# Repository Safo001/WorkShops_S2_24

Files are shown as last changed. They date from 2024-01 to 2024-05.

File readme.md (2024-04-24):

# WorkShops
## 1. [Build your Drone controller based on ESP-NOW](./workshop1/readme.md)
## 2. [CAD Design](https://github.com/UBRoboticsWorkshop/WorkShops_S2_24/tree/main/workshop2)
## 3. [Air Unit](https://github.com/UBRoboticsWorkshop/WorkShops_S2_24/tree/main/workshop3)
## 4. [Assembly and Power](https://github.com/UBRoboticsWorkshop/WorkShops_S2_24/tree/main/workshop4)

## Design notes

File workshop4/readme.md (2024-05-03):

# Assembling and Testing Your Drone
Firstly, make sure that you have all of your parts:

- Air unit
- 2x silver motors
- 2x black motors
- 4x propellers
- Capacitor
- ESC cable
- Air Unit
- 4 * Yellow Grommits
- Battery Cable

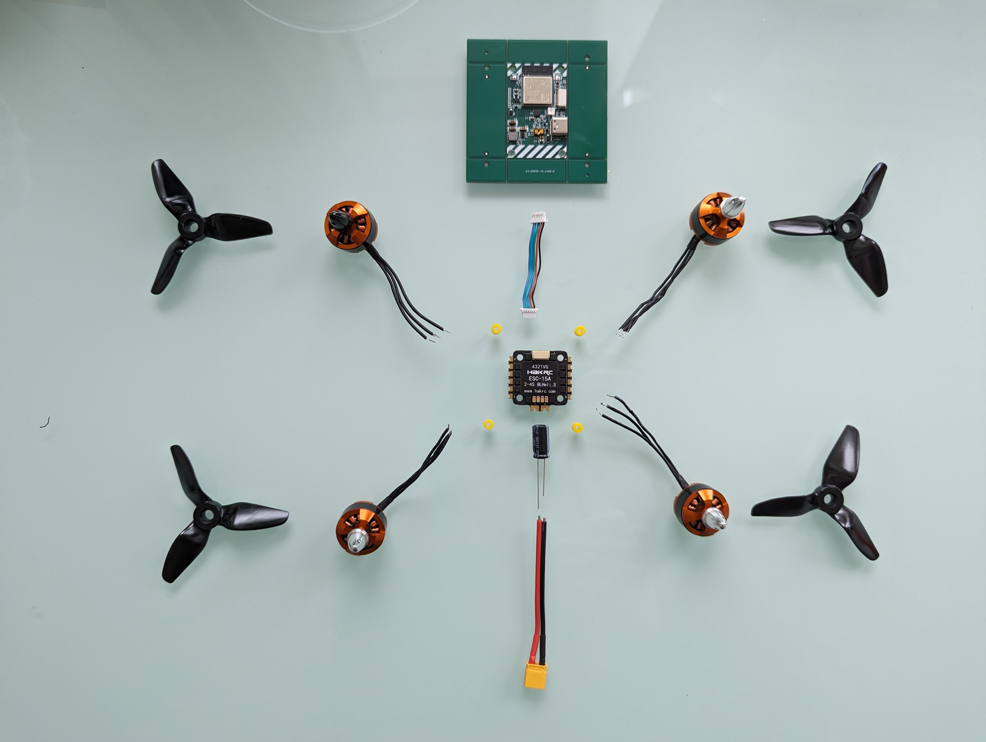
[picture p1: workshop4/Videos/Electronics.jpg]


And the printed parts:

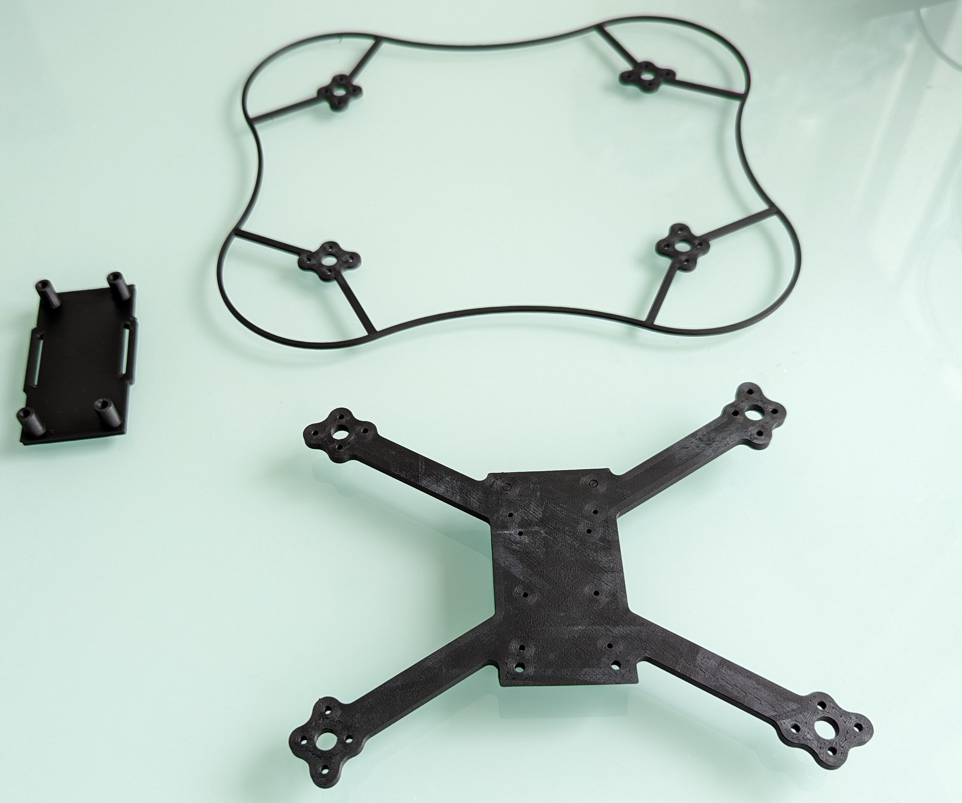
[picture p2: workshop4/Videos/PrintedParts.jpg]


- Propeller Guards
- Frame
- Battery mount

# Assembly 
Get your Air Unit ready by snaping off the rails, if you haven't already. 

Push 4 grommits into the Air Unit board. This can be a bit difficult, try squishing the grommit to squeeze it through the board.

https://github.com/UBRoboticsWorkshop/WorkShops_S2_24/assets/20403882/7c90dd00-24de-48df-a7dd-f99b9ae6fdc1

Remove the LiDAR cover, a thin orange file. Check carefully if it has already fallen off, otherwise you may scratch the LiDAR.

https://github.com/UBRoboticsWorkshop/WorkShops_S2_24/assets/20403882/bb20e618-9f44-439a-a1e0-7cc39bd59e51

Fit the ESC connector.

https://github.com/UBRoboticsWorkshop/WorkShops_S2_24/assets/20403882/d694c8c8-acc0-4bfe-938f-f40fce734783

Place the Air Unit into the cavity on the bottom of the frame, and use four M2 bolts to secure it.

https://github.com/UBRoboticsWorkshop/WorkShops_S2_24/assets/20403882/95f320fe-4e49-4986-b4f0-f9991f88dea0

Push 4 grommits into the 4 in 1 ESC.

https://github.com/UBRoboticsWorkshop/WorkShops_S2_24/assets/20403882/dd1053c3-97e8-4211-8c61-10d019f4d6c8

Use 4 M2 bolts to secure the 4 in 1 ESC to the top of the frame.

https://github.com/UBRoboticsWorkshop/WorkShops_S2_24/assets/20403882/43d65e90-b0f7-4e27-866d-42bc7dd63a49

Plug in the ESC cable

https://github.com/UBRoboticsWorkshop/WorkShops_S2_24/assets/20403882/b021f05e-f96a-4259-94c4-3d8d9a3c5d0e

Push some bolts through the frame and the guard, so as to align them. Next, screw the motor down onto it.

https://github.com/UBRoboticsWorkshop/WorkShops_S2_24/assets/20403882/b7a73cb8-1e47-4572-9239-a0372c5feb96

### Important! The motor nut propeller colours need to the in the same positions as in the videos, as they determine spin direction!

Solder on the motor wires. The best way to do this is to use your soldering stand to hold the wire against the side of the pad, such that the springiness of the wire puts a slight amount of pressure on the ESC. Clean your iron on the stand, before applying a very small amount of solder to the iron. This solder isn't to secure the wire, but to allow the liquid solder to better transfer heat than a dry iron. Let the pad heat up before you add more solder, and then hold the iron on the pad until the solder flows across it.

https://github.com/UBRoboticsWorkshop/WorkShops_S2_24/assets/20403882/3827fa9a-afa0-4dfc-aa05-6e3b26d2da30

https://github.com/UBRoboticsWorkshop/WorkShops_S2_24/assets/20403882/65c0ad6d-4bae-456d-b40d-aabbf710668b

Make sure to consider the angle you're soldering from. Put the iron on the side of the ESC away from the components, to reduce the risk of burning them.

The second best, but sometimes needed, way to solder on the wires is by first addind solder to the pad and then melting it while pressing the wire into it. Make sure that the insulation of the wire doesn't touch the solder, and be aware that the wire might heat up. This is a slightly questionable technique, but it's the easiest way to get the job done.

https://github.com/UBRoboticsWorkshop/WorkShops_S2_24/assets/20403882/1eaa0f6d-09d4-4b70-82b8-a107138e61ee

Next, solder the XT30 battery connector and capacitor to the ESC. Trim down the capacitor legs, and strip the insulation back on the battery wires. 

https://github.com/UBRoboticsWorkshop/WorkShops_S2_24/assets/20403882/044b5c15-248d-48de-9cad-c10328447741

Press the capacitor legs through the holes in the ESC pads, making sure that the polarity is correct (The capacitor will have a stripe to indicate negative, with minus signs on it. There should also be polarity markings on the ESC). Use the second hand to position the wire on the outside of the pad, and solder it down.

https://github.com/UBRoboticsWorkshop/WorkShops_S2_24/assets/20403882/d0c8200d-6cd6-4b8d-8212-d3770a6cd13c

Once you're sure the soldering is complete, mount the top part. If in doubt about a joint, call us over to check the joint before testing. 

https://github.com/UBRoboticsWorkshop/WorkShops_S2_24/assets/20403882/15de63a5-3043-421d-8a90-f4572b7fb201

# Testing
To test the power systems, we'll first use the bench supply. The main benefit of this is that a short circuit will cause a current cap rather than an explosion. Set the current to 500mA, to mitigate how much current can flow in this case, and the voltage to 11.1v. 

### Do not run the motors with the propellers connected! 

Upload the ESC testing sketech to the Air Unit, and disconnect the air unit from the computer. The system will now try to spin its motors 2.5 seconds after being connected to power.

Use the male XT30 connector with two leads soldered onto it to connect the bench supply, paying careful attention to the polarity. 

https://github.com/UBRoboticsWorkshop/WorkShops_S2_24/assets/20403882/5a78b0ef-956f-4ef9-ad18-9214dca81df2

The ESC will emit a series of beeps, then spin up the motors. Look closely at the screw threads on the motor outputs- They should be screwing downwards, like in this video:

https://github.com/UBRoboticsWorkshop/WorkShops_S2_24/assets/20403882/88b82665-31b5-4852-8465-4818063c72b0

If a motor is spinning backwards, it can be reversed by simply swapping two of the motor's wires. On a BLDC motor such as this, it doesn't matter which pair of wires are swapped- swapping any two will reverse it. You can use the technique described earlier of heating a solder blob and then inserting the wire to do this quickly.

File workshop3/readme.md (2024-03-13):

# Using the Air Unit

The Air Unit is similar to the ESP32 development board from Sumobots, however with additional systems on board to support flight. Some of the features of the Air Unit include:

- LiDAR, for millimetre altitude control
-	IMU, for rotation sensing to stabilize flight
-	Switching regulator, to allow direct supply from lithium batteries
-	8 GPIO pins broken out- these have a very small spacing though, so only try to use these if you’re very confident in soldering
-	USB-C, because at UBRobotics we live large 
-	RGB LED, added because our President Aswathy is a Gamer and she threatened to kick me off the committee if I didn’t make the drones replicate the exact colour fade she uses on her Cherry MX 2.0S Red Gaming Keyboard (with mechanical switches). Making the LED cover the full Adobe Wide Gamut RGB was the hardest part of the design, so you’d better appreciate it.

Through this tutorial, make sure to use the [code glossary](./CodeGlossary.md) included. 

# Step 1: Connect to the ESP32-S3
For this part, make a new sketch.

The Air Unit uses an ESP32-S3, which is a major upgrade from the base ESP32. One of the benefits is direct connection to USB, without a programming chip.

However, you’ll need to bootstrap it the first time. You can do this simply by holding down the BOOT button as you plug it in, to put it into boot mode. In this mode, it won’t run any code- it’ll just wait for a download.

Now you should see a port available for download and can proceed as normal. Under “Tools”, set the following settings:

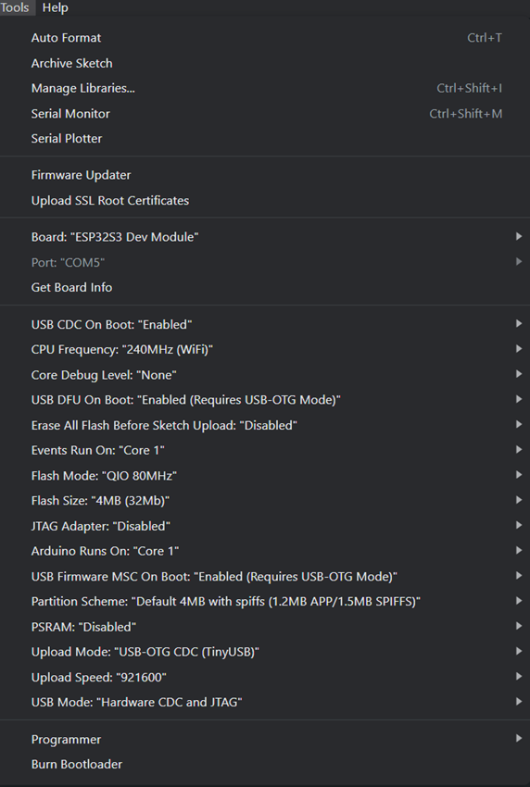
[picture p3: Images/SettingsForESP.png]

 
Hit upload with a blank sketch to save these settings to the ESP32-S3. If you can’t get the board to print text, make sure these settings are correct.

# Step 2: Hello World
From here, you can make an new sketch and write a simple “Hello World” program to check that the ESP32-S3 is working:

```cpp

void setup() {
  Serial.begin(115200);
}

void loop() {
  Serial.println("Hello World");
}
```

If successful, the unit will print Hello World very quickly into the serial monitor- the system is working. 

However, if you attempt to upload a new sketch you will probably see something like this:

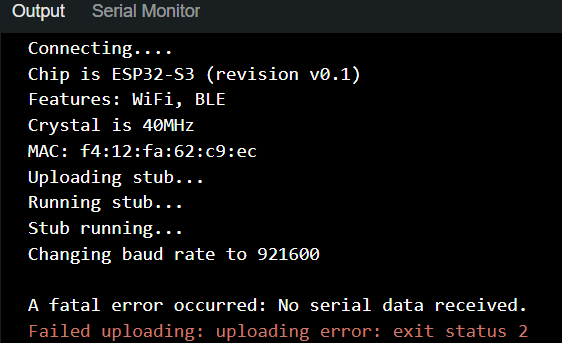
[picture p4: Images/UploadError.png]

 
This is because the USB connection is overloaded. This is a possible issue with the ESP32-S3 onboard USB, but it can be fixed by using the BOOT button.

Add a 1000ms delay into the sketch after the print statement, and then unplug the ESP32-S3. Hold down the button marked BOOT, plug in the USB cable and then release the BOOT button. You should be able to see this message in the serial terminal:

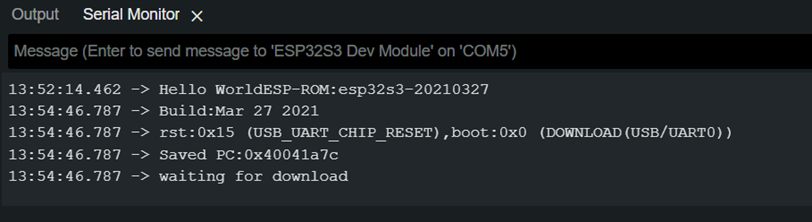
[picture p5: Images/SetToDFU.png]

 
Uploading should now be successful, and the program will run after you reboot the ESP32-S3- this time printing the text once per second. From here, you can upload the code without using the BOOT button. If there are issues with uploading to the ESP32-S3, try the BOOT button to recover it.

When working with UAVs, the main loop will run thousands of times per second, which means a print statement in the main loop can cause the ESP32-S3 to lock up.

You can also tap the reset button instead of unplugging the Air Unit.

# Step 3: Using the LED

This section is on the LED_TEST sketch.

Unlike the LEDs last semester, the Air Unit has a WS2812 addressable LED allowing digital colour and brightness control. It’s also a little bit brighter than a regular LED.

Use ```neopixelWrite()``` to set the colour of the LED, which is connected to pin 48. 

You can use ```(brightness+brightness*sin(i)/2)``` to have the brightness of each channel fade smoothly between zero and brightness.

```cpp
const int brightness = 27;

void setup() {
 
}

float i;
void loop() {
  delay(10);
  i+=0.1;
  //Put your neopixel code here
}
```

To test how long this command takes, create a variable called:

```long startTime, endTime;```

Set ```startTime``` to ```micros()``` before the code to be measured, and ```endTime``` to ```micros()``` once it has run. You can then read out the difference between the two out on the serial monitor. How long does this command take?

For dynamic systems, it’s important to make sure that your code can run fast enough to react to changes in the environment. The ESP32 has two cores, so you can put code like this which isn’t time critical on one, and the more important code on the other.

# The IMU

Simple sensors, such as a thermistor, use analog signals to communicate; in more advanced systems it’s common to find serial communications used. The Inertial Measurement Unit (IMU) on this board uses Serial Peripheral Interface (SPI) to communicate.

## Registers

Most serial devices use what is known as a register map. The register map for the MPU6500 can be found [here](https://invensense.tdk.com/download-pdf/mpu-6500-register-map)

A register map is like a table, where each “register” is a location which holds a value- these are effectively variables stored on the sensor. These values can either control the behaviour of the sensor, or hold information to be read. Some registers can be both written and read, while others have controlled access.

## SPI
The Serial Peripheral Interface uses four lines:

<img width="600" src="https://github.com/UBRoboticsWorkshop/WorkShops_S2_24/blob/main/Images/SPI.png">
 
Credit: Analog Devices

•	The CS line allows for a device to be selected without an address being broadcast, which saves time
•	MOSI is data travelling out from the ESP32-S3
•	MISO is data travelling out from the IMU
•	SCLK is the clock signal, which allows for data to be read on the MOSI/MISO lines at the right time

The IMU can run SPI at 2,000,000 bits per second for all of its registers, and 20,000,000 for the main data registers.

If you want to learn more about SPI, have a look at [this](https://learn.sparkfun.com/tutorials/serial-peripheral-interface-spi/programming-for-spi)

# Step 4: Reading From the IMU	

This section is in the IMU_CONNECT sketch.

The following is a snippet of code that is used to check the IMU is working before the aircraft takes off:

```cpp
// IMU Check Before Takeoff

#include <SPI.h>

#define MPU6500_NCS 18
#define MPU6500_ID 0x70
#define WHO_AM_I_REG 117
#define READ_BIT_MASK 0x80

SPIClass *IMUHSpi = NULL;

void setup() {
  Serial.begin(115200);

  IMUHSpi = new SPIClass(FSPI);
  setupIMUSPI(IMUHSpi);

  if (readIMURegister(WHO_AM_I_REG) != MPU6500_ID) {
    Serial.println("IMU not found. Takeoff may result in an unpleasant day.");
    Serial.print("WHO AM I register returned: 0x");
    Serial.println(readIMURegister(WHO_AM_I_REG), HEX);
    while (1) {
      ; // Halt program on error
    }
  } else {
    Serial.println("IMU found");
  }
}

void loop() {
  // Main loop
}

int readIMURegister(int registerAddress) {
  int readCommand = 0;
  int regData = 0;
  return regData;
}

void setupIMUSPI(SPIClass *IMUHSpi) {
  pinMode(MPU6500_NCS, OUTPUT);
  digitalWrite(MPU6500_NCS, HIGH);

  IMUHSpi->begin(17, 15, 16, 18);  // Customize these pin numbers as needed
  IMUHSpi->setFrequency(1000000);
  IMUHSpi->setDataMode(SPI_MODE0);
  IMUHSpi->setBitOrder(MSBFIRST);
}
```

In this code, the function ```readIMURegister()``` takes a register to read and returns the value of the register. 

Run this code, and check what is said in the serial monitor. The IMU won’t be found, because ```readIMURegister()``` doesn’t do anything (causing “ an unpleasant day”).

Using ```digtalWrite()``` and ```IMUHSpi->transfer()```:

1.	Set the NCS pin to low
2.	Send the register address with the first bit set to one (to indicate a write command) to the IMU
3.	Transfer 0x00 to the IMU, and save the response to regData to be returned 
4.	Set the NCS pin back to high

When it works, it should print “IMU found”. Some of the IMUs may return a value of ```0x71```, if this is the case just change the definition.

<details>
  <summary> <b> Hint: SPI comms  </b>  </summary>
  
To make this work, use ```digtalWrite()``` to set ```MPU6500_NCS``` (Pin 18) to LOW, which tells the IMU to expect communications. 

An outgoing message can be either a read command or a write command, identified by the first bit being a 1 for read or 0 for write.

registerAddress will be a value from 0-127. It’ll need to be a value from 128-255 to read. We can use Boolean operations to make this so- this is known as “setting a bit”. To set the leftmost bit to one, we can use: 

```cpp
registerAddress | 0b10000000
```

```0b``` tags the number as a binary number. However, this is not very readable so we can use hexadecimal instead.

```cpp
registerAddress | 0x80
```

This is the same number (127), but represented as hexadecimal. Using compiler commands we can make it even more readable. There is a line at the top of the sketch:

```cpp
#define READ_BIT_MASK 0x80
```

This line of code will not be uploaded to the ESP32 S3. Instead, it tells the compiler to replace every instance of "```READ_BIT_MASK```” with “```0x80```”. Be careful- it won’t take context into account! If you misuse compiler commands, for example defining a value for “int”, the compiler will replace every single “int” with this definition of it.

Use  ```IMUHspi->transfer()``` to send ```reg | 0x80```. Then, send ```0x00``` and save the number it returns to ```regData```. Note that because we’re using a pointer to refer to the SPI bus instead of using it directly, we use “->” rather than “.” to address member functions. 

Finally, set pin ```MPU6500_NCS``` to ```HIGH```, in order to end the communication.

</details>

# Step 5: Read Faster

Use the IMU_SEQUENTIAL_READ sketch for this part.

If we want to read the IMU data, there are 12 registers to read- 6 different values, with two bytes each. It’s not very quick to read each register, end the communication, start it again, address the next register, so on, so on.

Instead, we can simply read the first register and then keep sending ```0x00```. This will trigger a sequential read, moving down the register table each time. Not all devices support this, but all of the good ones do.

Annoyingly, Invensense decided to put thermometer data right in the middle of the data we actually care about. Great prank guys.

However, it’s still quicker to read all 14 bytes at once than two blocks of 6, so I guess your drone now doubles as an Internet of Things home assistant AI central heating blockchain enabled flying thermostat or something. 

Anyway, here’s the code:

```cpp
#include <SPI.h>

#define MPU6500_NCS 18
#define MPU6500_ACC_X_L 59
#define READ_BIT_MASK 0x80

SPIClass *IMUHSpi = NULL;
byte imuDataRawAccGyro[14];

void setup() {
  Serial.begin(115200);

  IMUHSpi = new SPIClass(FSPI);
  setupIMUSPI(IMUHSpi);
}

void loop() {
  readIMUSPI(59, 14, imuDataRawAccGyro);
  for (int i = 0; i < 14; i++) {
    Serial.print(imuDataRawAccGyro[i]);
    Serial.print("\t");
  }
  Serial.println();

  delay(250);
}

void readIMUSPI(int registerAddress, int count, byte data[]) {
	
}

void setupIMUSPI(SPIClass *IMUHSpi) {
  pinMode(MPU6500_NCS, OUTPUT);
  digitalWrite(MPU6500_NCS, HIGH);

  IMUHSpi->begin(17, 15, 16, 18);  // Customize these pin numbers as needed
  IMUHSpi->setFrequency(1000000);
  IMUHSpi->setDataMode(SPI_MODE0);
  IMUHSpi->setBitOrder(MSBFIRST);
}

```

Once again, fill in the blanks for ```readIMUSPI(int reg, int count, byte data[])```
1.	Pull CS low
2.	Send a register address, with first bit set to indicate “read”
3.	Iterate through the ```data[]``` array with a for loop, transferring ```0x00``` and storing the responses in ```data[i]```
4.	Pull CS low high to end the communication

Since all arrays are passed by reference, any changes made to ```data[]``` will persist outside ```readIMUSPI()```- there’s no need to return anything.

When this code works, you should see a ton of numbers being printed in the Serial terminal- they won’t seem to mean anything, but will change when the board is moved.

Except the two bytes for temperature. They’ll change when the temperature changes. Thanks Invensense.

# Step 6: Processing the Data

Keep using the IMU_SEQUENTIAL_READ sketch for this part.

The data is returned as a high byte and a low byte- these are two 8 bit numbers that can be concatenated (added end to end) in binary to form one signed 16 bit number, as shown below:

| | -32768 | 16384 | 8192 | 4096 | 2048 | 1024 | 512 | 256 | 128 | 64 | 32 | 16 | 8 | 4 | 2 | 1 |
|---|---|---|---|---|---|---|-----|-----|-----|----|----|----|--|---|---|---|
| High Byte | 1 | 0 | 0 | 1 | 1 | 0 | 1 | 0 | | | | |  | | | |
| Low Byte  | | | | | | | | | 1 | 1  | 1  | 0  | 1 | 0 | 1 | 1 |

the high byte is 10011010 in binary which represents 154 in decimal.

the low byte is 11101011 in binary which represents 235 in decimal.

When we add them together, the first bit becomes negative creating -25877 in decimal.

The reason the numbers are so erratic is that some are high bytes, others low bytes, and all unsigned while the data is signed.

To process this, we’ll use the left bit shift function << and or function |. You can use the register map to see what data is stored where.

Create seven ```int16_t``` variables, named with their contents. Then for each left shift the high byte and combine it with the low byte. Finally, print them all out so they can be read.

<details>
  <summary> <b> Hint: Combining Bytes </b> </summary>
  
  The high byte must be moved 8 places left, so use: 
  
  ```cpp
  int16_t data1;
  data1 = imuDataRawAccGyro[0] << 8 | imuDataRawAccGyro[1];
```
to combine the two readings into one 16 bit number that can be positive or negative.

</details>

<details>
  <summary> <b> Hint: Register Maps  </b>  </summary>
  
The read starts at 59 and has a length of 14. This means the following registers are read:
 
The variables, in order, should be:

```cpp
int16_t accX, accY, accZ, temperature, gyroX, gyroY, gyroZ;
```

_H means high byte, and _L means low byte. The array will have them in order, so simply assign 0 and 1 to accX, 2 and 3 to accY and so on.

</details>

## Interpreting the Results

The accelerometer data measures linear acceleration, which lets it pick up both gravity and motion. The gyroscope picks up angular velocity.

If you rotate the board 90 degrees horizontally, you should see one ACC value becomes zero whilst another becomes high. While the board is rotating, one of the gyro channels will be high but will fall to zero when the rotation stops.

In the sensor fusion workshop, we’ll look at how to eliminate errors from this data and process it into something we can react to.

# Using the LiDAR

The board has a VL53L1 LiDAR, with up to 8 meters of range in ideal conditions. This will allow for your drone to maintain a steady height, making learning to fly much easier.

The LiDAR uses I2C, which is slower than SPI but uses less pins and is more suitable for large numbers of sensors which are only read occasionally. Our gyro will be read at 2KHz, while the LiDAR will only be read at about 30Hz.

For this one, I have ported the STMicroelectronics driver to be compatible with ESP32. Instead of programming a driver, like with the MPU6500, you’ll be working with the API.

This is very good news for you because there is no register map for the VL53L1. The reason for this, and I promise robotics member that I would not lie to you, is: 

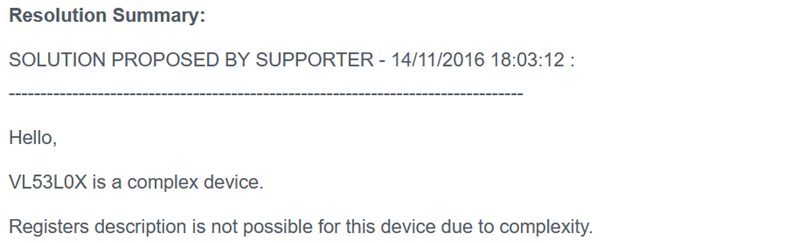
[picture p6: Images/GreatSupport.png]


# Step 7: Using the VL53L1 ULD

For this step, use the VL53_DRIVER sketch. This also has a header file where a lot of register names are defined, so I've packed them together as a .ZIP file. You'll need to uncompress this to open the sketch.

A useful feature on the Arduino IDE 2.0 is code folding- hover to the left of a function and an arrow should appear. Click this to minimize the	 function to one line, making it easier to quickly read over the code. You can use this to collapse all of the API functions, so that you can quickly read them in the next section and find which function corresponds to each step.

In setup, add a line of code to the while loop to set the booted variable to the boot state of the VL53. Then, call the iniLiDAR function to flash the default settings to the VL53.

In the main loop, make the while loop check if data is ready. next use the corresponding functions to set range and status. Range will be the distance in mm, and status will return 0 if the data is good.

Once you’ve done that, clear the interrupt to have the VL53 start another read.

One last thing- there should be a little plastic cover over your LiDAR. The optics are somewhat fragile, and this is there to protect them. However, to get accurate readings you’ll need to permanently remove this by peeling it off with the small tab below the optics. It might have already fallen off, so be careful not to scratch the lens.

# Next steps
The main thing to focus on from here is working on your drone frame. Remember, it's not just about being strong enough to fly- you'll also want it to survive a crash and be rigid enough to suppress vibrations.

Next session, we'll be looking at how to turn these numbers into useful flying. However, you'll want to make your drone frame now so that you have time to tweak and improve it.

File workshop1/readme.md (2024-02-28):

# Build your Drone controller based on ESP-NOW

---
As many of you found out during Sumobots, using an Access Point and TCP or UDP to communicate with your robot can cause a lot of issues- latency and disconnects being two major issues. For an FPV drone, this isn't good enough.
Today, we'll be looking at using the ESP32's built in proprietary communication systems to achive much better control. 

(You can even reuse this in sumobots next year to stomp first years)

Today's workshop will be a fairly simple reintroduction to robotics, however in our next session we will start to take a deeper look into low level programming and hardware to start using the flight controller.

## 1. ESP-NOW

<p align="center">

</p>

- **What exactly is ESP-NOW? Why do we need it?**

ESP-NOW is a wireless communication protocol that allows multiple devices to connect to each other without using a central WiFi network.

- **We will also be using Arduino IDE for this project. Just to clarify, **

<p align="center">

</p>

This is the interface you will be pasting your code on. 

- **How it works**
  You don't need an initial WiFi network. All you need is an initial pairing with another device, but after pairing, the connection is peer-to-peer.
---
## The whole code: https://github.com/UBRoboticsWorkshop/ESP-NOW-controller/tree/main
---
## 1. Build your first controller with a breadboard

<p align="center">[video](https://youtu.be/tSLb4vP00uo)</p>

> [!NOTE]
> All pins on ESP32 only accept 3.3v.

- **Schematic diagram:**
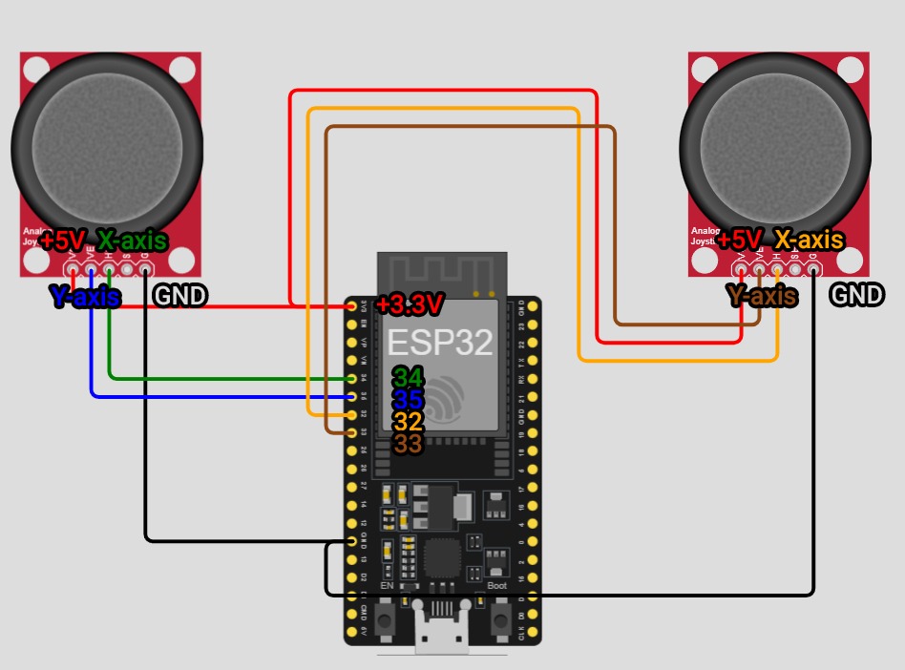
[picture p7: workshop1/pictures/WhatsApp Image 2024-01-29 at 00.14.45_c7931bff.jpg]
Schematic diagram

---
> **The following part is the code used to send the message. You need to work with another group. One is the sender and one is the receiver.**

> [!NOTE]
> You need to know the MAC address of the TX and RX devices.
> You need to set the TX and RX devices on the same channel.
> You MUST NOT change the TX power.
> You can ONLY INCREASE the TX delay function.
---
## 2. Get the MAC Address

> A MAC (Media Access Control) address, referred to as a hardware or physical address, is a unique, 12-character alphanumeric attribute that is used to identify individual electronic devices on a network. An example of a MAC address is 00-B0-D0-63-C2-26.

- **First, you need to know the MAC address of the Rx device you want to send to. By flashing the following code into the receiver, you can get the MAC address.**
```cpp
#include "WiFi.h"
 
void setup() {
  Serial.begin(115200);
  WiFi.mode(WIFI_STA);
}
 
void loop() {
  delay(5000);
  Serial.print("My Mac is:");
  Serial.println(WiFi.macAddress());
}

```
- **We also recommend you record the Tx device MAC address as well, as we need to check the identity of the sender later.**

---
## 3. Tx code
> Code for the transmitter
### 3.1 Header part (create a head file(.h) with the same name of your .ino file)
This can be done by clicking the three dots at the top right of the Arduino IDE, and then pressing new tab. Name this file ESPNOW_Transmitter.h.
- **Include libraries: We need esp_now, WiFi and Arduino library. They are all installed by default. You can simply include them.**
```cpp
#include <esp_now.h>
//#include <esp_wifi.h>
#include <WiFi.h>
#include <Arduino.h>
```

- **Create variables: WiFi channel, Rx MAC, and data for the receiver**
```cpp
// Set the wifi channel (1-13)
#define channel_ 6

// REPLACE WITH YOUR RECEIVER MAC Address
uint8_t RxMacAddr[] = {0xFF,0xFF,0xFF,0xFF,0xFF,0xFF};

struct PacketData {
  uint16_t lxAxis;
  uint16_t lyAxis;
  uint16_t rxAxis;
  uint16_t ryAxis;
 
  uint16_t ch1;
  uint16_t ch2;
  uint16_t ch3;
  uint16_t ch4;  
  uint16_t ch5;
  uint16_t ch6;
  uint16_t ch7;
  uint16_t ch8;  
} data;
```

- **A function that helps to reduce the drift of the joystick.**
```cpp
uint16_t ReMap(uint16_t value, bool reverse) {
  if (value >= 2200) {
    value = map(value, 2200, 4095, 2048, 4095);
  } else if (value <= 1800) {
    value = (value == 0 ? 0 : map(value, 1800, 0, 2048, 0));
  } else {
    value = 2048;
  }

  if (reverse) {
    value = 4095 - value;
  }
  //Serial.println(value);  
  return value;
}
```
### 3.2 main cpp file (.ino)
- **Include the head file you created. (replace with your header file name.)**
```cpp
#include "ESPNOW_Transmitter.h"
```

- **Setup part:**
```cpp
void setup() {
  Serial.begin(115200);
```
- **Set WiFi into the SAT mode. Set the channel (there are 13 channels in total for 2.4 GHz WiFi). Set the power to -1 dBm**
> [!NOTE]
> Please do not change the power. The ESP32 generates a lot of heat during transmission. If you change it it will kill the chip and burn yourself.
```cpp
  WiFi.mode(WIFI_STA);
  WiFi.channel(channel_);
  WiFi.setTxPower(WIFI_POWER_MINUS_1dBm);
```
- **Turn on esp-now by add peers(The Rx device)**
```cpp
  if (esp_now_init() != ESP_OK) {   // Init ESP-NOW
    Serial.println("Error initializing ESP-NOW");
  } else {
    Serial.println("Succes: Initialized ESP-NOW");
  }

  // Register peer
  esp_now_peer_info_t peerInfo = {};
  memcpy(peerInfo.peer_addr, RxMacAddr, 6);
  peerInfo.channel = 0;  //current WiFi chennel
  peerInfo.encrypt = false;
  
  // Add peer        
  if (esp_now_add_peer(&peerInfo) != ESP_OK) {
    Serial.println("Failed to add peer");
    return;
  } else {
    Serial.println("Succes: Added peer");
  } 
```
- **Enable input pins for joysticks**
```cpp
  // joystics
  pinMode(32,INPUT);
  pinMode(33,INPUT);
  pinMode(34,INPUT);
  pinMode(35,INPUT);
  //keys
  //pinMode(19,INPUT_PULLUP);
  //pinMode(21,INPUT_PULLUP);
  //pinMode(22,INPUT_PULLUP);
  //pinMode(23,INPUT_PULLUP); 
}
```
- **Loop function**
```cpp
void loop() {
```
- **Read the voltage from pins and remap the value**
```cpp

  data.lxAxis    = ReMap(analogRead(32), false);
  data.lyAxis    = ReMap(analogRead(33), false);
  data.rxAxis    = ReMap(analogRead(34), false);
  data.ryAxis    = ReMap(analogRead(35), false);
```
- **Send the message**
```cpp
  esp_now_send(RxMacAddr, (uint8_t *) &data, sizeof(data));
```
- **Delay**
```cpp
  delay(5); //chip temperature issue
}
```

---
<details>
<summary>

## 4. Rx code (Try to read and understand by yourself. Feel free to ask.)
</summary>

### 4.1 Header
```cpp
#include <esp_now.h>
//#include <esp_wifi.h>
#include <WiFi.h>
#include <Arduino.h>

// Check Tx identity
//#define CheckMac

// Set the wifi channel (1-13)
#define channel_ 6

// REPLACE WITH YOUR RECEIVER MAC Address
uint8_t TxMacAddr[] = {0xA8,0x42,0xE3,0xCD,0x5F,0x04};

// Timeout
#define SIGNAL_TIMEOUT 100 //ms
unsigned long lastRecvTime = 0;

struct SystemStatus{
  unsigned int DataUpdateSpeed;
  bool timeout;
  char StrMac[18];
} sys_status;

struct PacketData {
  uint16_t lxAxis;
  uint16_t lyAxis;
  uint16_t rxAxis;
  uint16_t ryAxis;
 
  uint16_t ch1;
  uint16_t ch2;
  uint16_t ch3;
  uint16_t ch4;  
  uint16_t ch5;
  uint16_t ch6;
  uint16_t ch7;
  uint16_t ch8;  
} data;

void printMAC(const uint8_t * mac_addr){
  char macStr[18];
  snprintf(macStr, sizeof(macStr), "%02x:%02x:%02x:%02x:%02x:%02x",
          mac_addr[0], mac_addr[1], mac_addr[2], mac_addr[3], mac_addr[4], mac_addr[5]);
  Serial.print(macStr);
}
```

### 4.2 Main cpp
```cpp
#include "ESPNOW_Receiver.h"

// callback function that will be executed when data is received
void OnDataRecv(const uint8_t * mac, const uint8_t *incomingData, int len) {
#ifdef CheckMac
  char MACAd[6];
  memcpy(&MACAd, mac, sizeof(MACAd));
  for (int i = 0; i < 6; i++) {
    if (MACAd[i] != TxMacAddr[i]) return;
  }
#endif

  snprintf(sys_status.StrMac, sizeof(sys_status.StrMac), "%02x:%02x:%02x:%02x:%02x:%02x",mac[0], mac[1], mac[2], mac[3], mac[4], mac[5]);

  // get RSSI
  //wifi_pkt_rx_ctrl_t wifi_rx_status;

  // check the identity of Tx

  memcpy(&data, incomingData, sizeof(data));
  lastRecvTime = millis(); 
}

void setup(){
  Serial.begin(115200);
  WiFi.mode(WIFI_STA);
  WiFi.channel(channel_);

  //ESP_ERROR_CHECK(esp_wifi_set_channel(channel_, WIFI_SECOND_CHAN_NONE));

  ESP_ERROR_CHECK(esp_now_init());

  esp_now_register_recv_cb(OnDataRecv);
}

void loop(){
  // check the data speed and update status
  sys_status.DataUpdateSpeed = millis() - lastRecvTime;
  if (sys_status.DataUpdateSpeed > SIGNAL_TIMEOUT ) {
    sys_status.timeout = true;
  } else {
    sys_status.timeout = false;
  }

  // print out the data
  Serial.print("ReMsg from: ");
  Serial.print(sys_status.StrMac);
  Serial.print("  Time cost:");
  Serial.print(sys_status.DataUpdateSpeed);
  Serial.print("  lx:");
  Serial.print(data.lxAxis);
  Serial.print("  ly:");
  Serial.print(data.lyAxis);
  Serial.print("  rx:");
  Serial.print(data.rxAxis);
  Serial.print("  ry:");
  Serial.print(data.ryAxis);
  // Other chennels
  Serial.println();

  // Drone control & PID loop
}
```

</details>

## 28th Feb - New Parts



NOTE: This model is a prototype and a basic idea for your team to build from. Please explore innovative ways to design your own controllers!!! It may be a good idea to think about ways that the circuitry can be encased...

Please follow this video for soldering :

(1) Solder ESP to Perfboard

https://github.com/UBRoboticsWorkshop/WorkShops_S2_24/assets/110237339/7468711a-e8a6-4a86-9586-cd83d3d7a7a9

(2) Solder Joysticks to Perfboard

Good quality Vido : https://drive.google.com/drive/folders/1UYhm-c77dL-LISOzTpersRXsNKGeuwwQ?usp=sharing

Sorry for the bad quality (sam vid as google drive link)
https://github.com/UBRoboticsWorkshop/WorkShops_S2_24/assets/110237339/f3f0fe57-48ea-4473-86bf-81150caa7db5

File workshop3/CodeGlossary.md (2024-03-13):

# Code Dictionary
## General
```cpp
void neopixelWrite(uint8_t pin, uint8_t red_val, uint8_t green_val, uint8_t blue_val)
```
Sends a data packet to an addressable LED. This accepts a pin number, and 3 values from 0-255 to set the brightness of each colour.
This uses RMT, which uses long pulses and short pulses to represent 1 and 0 respectively.

```cpp
unsigned long micros()
```
Returns the number of microseconds the sketch has been running

```cpp
uint8_t transfer(uint8_t data)
```

Transmits a byte of data on MOSI, and listens for a byte of data on MISO

```cpp
void digitalWrite(uint8_t pin, uint8_t val)
```

Sets pin number “pin” to “val”. False, LOW or 0 sets it low, while anything else sets it high.

```cpp
int variableToShift << int placesToShift 
```

Left shift- moves each bit in variableToShift left, placesToShift times. This is equivalent to multiplying "variableToShift" by 2^ "placesToShift" with integers.

```cpp
int variableA | int variableB
```
Bit-wise or- combines two variables by performing an "or" function on each pair of bits. 

## VL53L1 ULD
```cpp
int bootState()
```
Returns 1 if booted, 0 if not. Make sure to wait until the sensor is fully booted before trying to init, or your LiDAR firmware will become a mystery box

```cpp
void initLiDAR()
```
Flashes a default config to the LiDAR and has it begin ranging

```cpp
boolean dataReady()
```
Returns true if the LiDAR has new data. Can also be replaced with reading the GPIO interrupt pin

```cpp
int getRange()
```
Returns the measured distance, converted to mm

```cpp
uint8_t getRangeStatus()
```
Zero means the current range is valid, anything else means panic (or out of range).

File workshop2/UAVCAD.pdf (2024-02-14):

# CAD for UAVs

Welcome to our second workshop, CAD for UAVs. If you’ve attended our Sumobots workshops, you should probably be quite familiar with Fusion 360 by now. If not, feel free to reference our previous workshops- they’re still available on the GitHub.

(https://ubroboticsworkshop.github.io/WorkShops/1_cad/ will cover how to import parts and create new parts to hold them together)

A UAV will experience loads far greater than a Sumobot, with much more reason to cut down weight. In order to have your drone approved for flight, you’ll have to run a static loading simulation and pass an inspection.

Unlike in Sumobots, where the focus was teaching basic use of CAD tools, the focus of this workshop will be to show you the tools and techniques that will allow you to iterate and improve your design.

For the time being, don’t worry too much about creating a super lightweight aerodynamic frame- it’s better to create an overbuilt one that can take a hit, then work on cutting down the weight as you become more experienced at both CAD and flying.

You’ll also need to design a propeller guard that has a radius of at least 78mm, to protect from ground strikes. This doesn’t need to be very strong, just enough to stop a propeller strike in a rough landing.

If you want to get straight into simulations, I’ve provided a .STEP file of a drone frame you can use however I’d recommend you design your own and then simulate on that. The given drone frame has also been pre-simplified to make simulation easier.

# Placing components

Below is an image showing how you may choose to lay out your components:

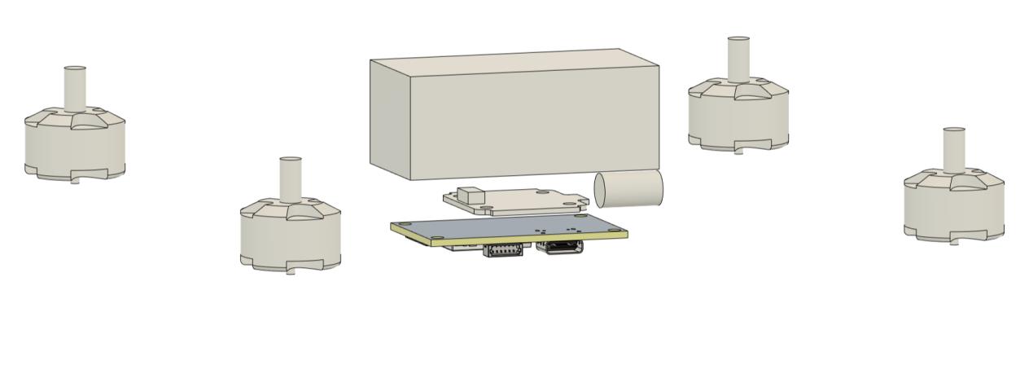
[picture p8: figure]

A few things to consider:

Keep the antenna away from any wires carrying high current.

Make sure the LiDAR can see the floor.

Give ample room between the propellers and the battery (at least 45mm for 75mm propellers).

Make sure you can program using the USB-C port, leave enough room around the connector for thick cables.

Make sure you can connect the Air Unit and the motor
driver board.

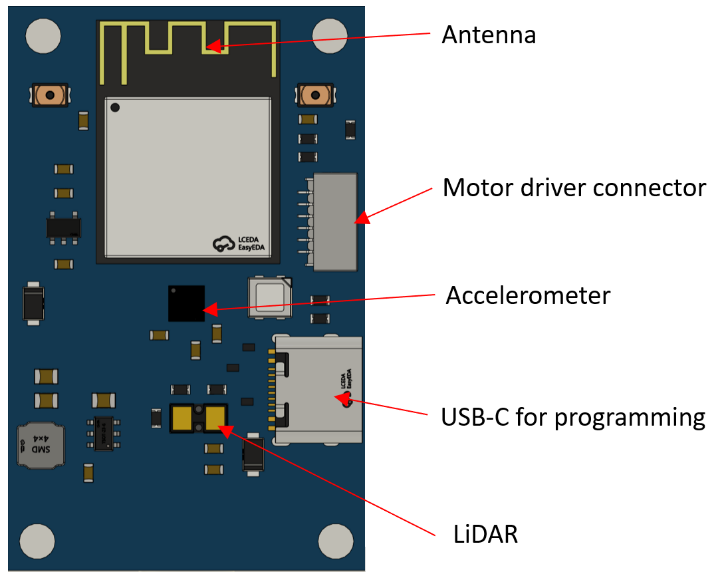
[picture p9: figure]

Don’t move the accelerometer too far away from the centre of mass.

Put a cover over the air unit so that it won’t be damaged in a crash.

The circular capacitor on the motor driver can be moved but must be kept close to the motor driver.

Make heavy use of the project tool to add mounting holes.

The Air Unit will be mounted with grommets that accept 2mm screws.

# Designing a Frame

Files for the main components- Air unit, motor, battery and ESC- are provided.

- Remember to add some size on your motor mounting holes- the 2mm motor mounting holes should be at least 2.4mm if it’s 3D printed. Also, the motor’s spindle protrudes out of the base so make sure to leave a hole for it- 6mm should be enough.
- The propeller’s diameter is 75mm, but you’ll want to leave ample room between them and the frame.
- I have given an OBJ file of the demo drone. This Drone is overbuilt and could be a lot lighter if optimized properly; this model can work as a reference for a functioning drone though.

# Forces on a drone

The drone moves by rotating to point in the direction that it intends to accelerate in. In order to rotate, and resist external forces, the drone changes how fast each motor is spinning. We’ll look into this process and how to control this in a future workshop, but for now we just need to consider how these corrections might put stress on the frame.

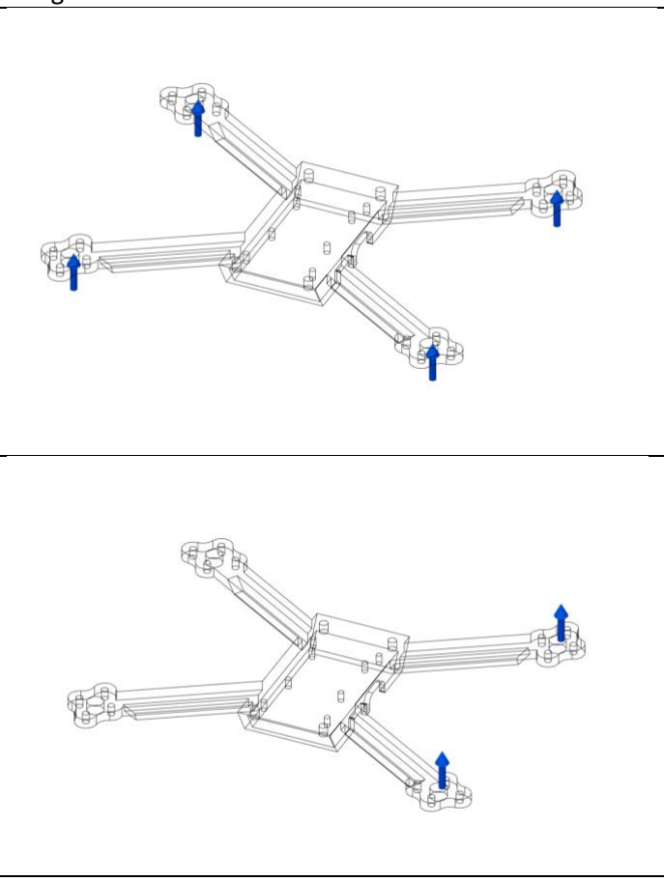
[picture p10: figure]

State | Motor signal | Image
Hover | All motors provide the same thrust
Rolling | Motors on the left or right increase speed

Pitching | Motors at the front or back increase speed
Yawing | To turn the aircraft, diagonal motors produce more thrust. Since these motors are both spinning in the same direction, the drone will turn.

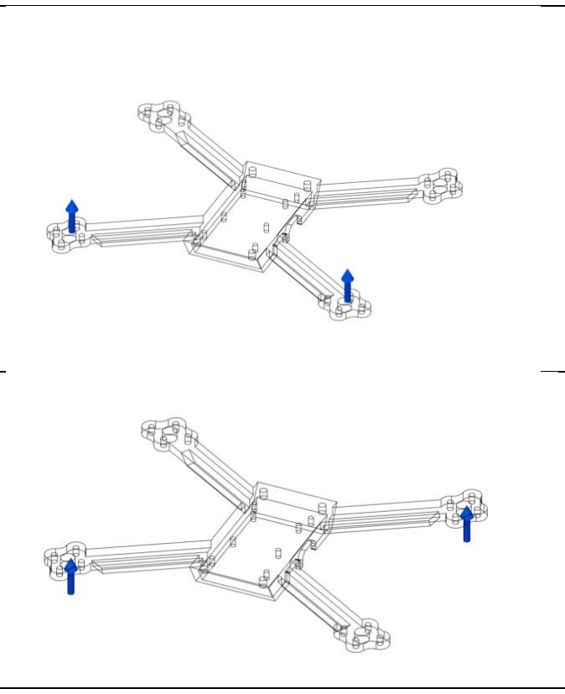
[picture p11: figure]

The firmware for the flight controller limits how much throttle can be used to make these corrections, so the slower motors will not actually turn off during flight.

# Setting up a Static Loading Study

1. Select the environment tab, and switch to Simulation:

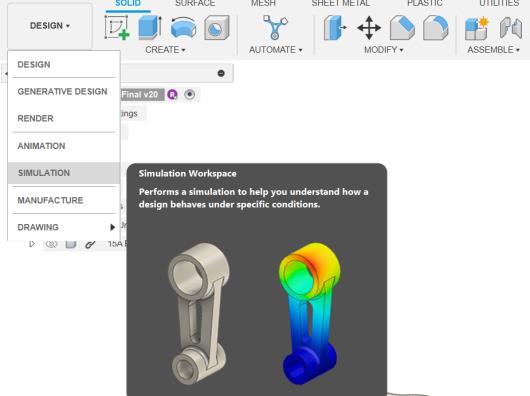
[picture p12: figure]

2. Select static stress.

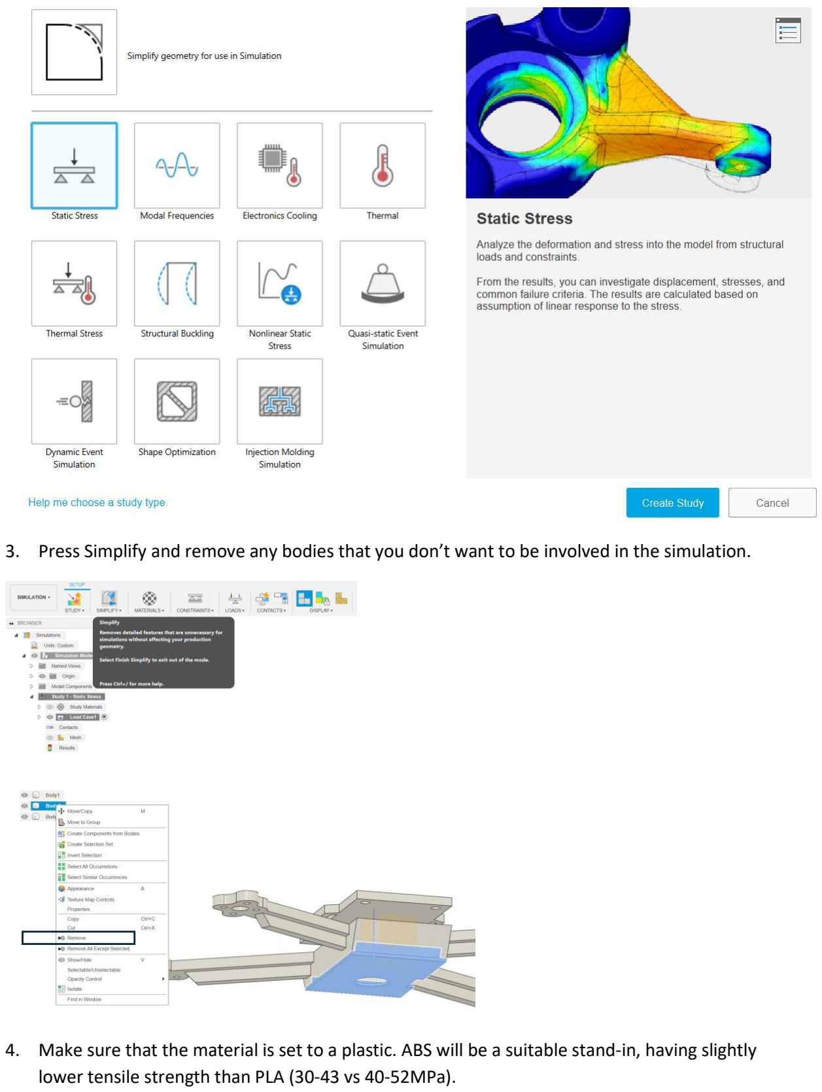
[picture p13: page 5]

3. Press Simplify and remove any bodies that you don’t want to be involved in the simulation.
4. Make sure that the material is set to a plastic. ABS will be a suitable stand-in, having slightly lower tensile strength than PLA (30-43 vs 40-52MPa).

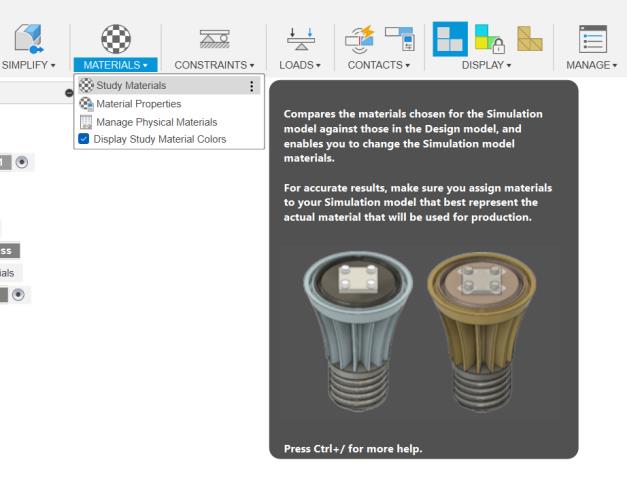
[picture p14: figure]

5. Use the Loads tab to add structural loads to your frame.

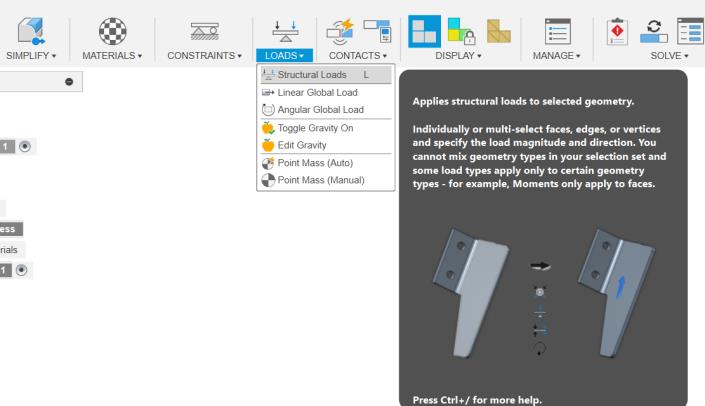
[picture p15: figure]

6. Select the point at which the motor will apply force, the mountings. When using a 3040 propeller, the 1806 BLDC can create about 2N of force.

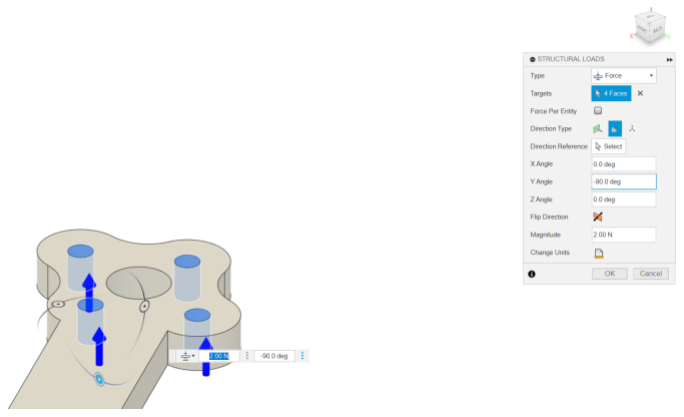
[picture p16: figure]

7. Apply loads to all limbs. It may prove useful to experiment with how the UAV reacts to different situations- hovering, maximum acceleration upwards, turning in various axis.
8. Add structural constraints- the battery mounts should be considered the anchor point, since the weight of the air unit and the ESC are negligible.

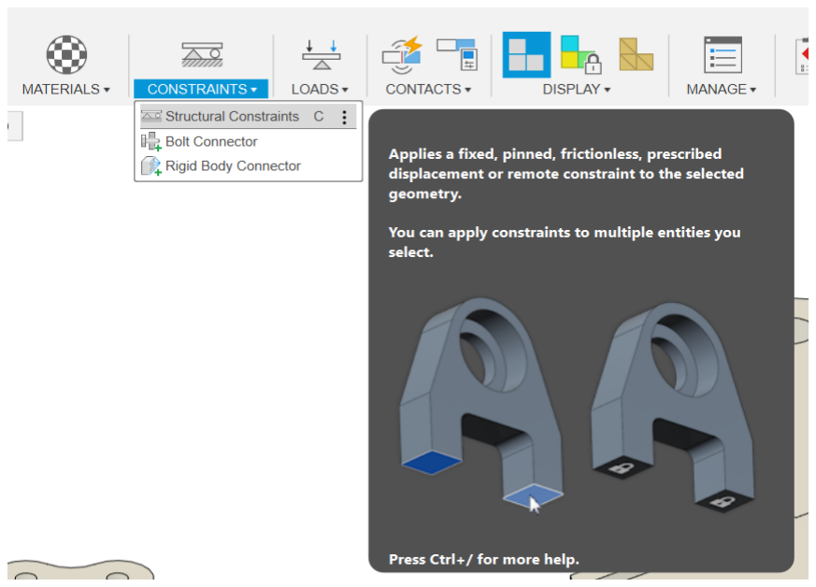
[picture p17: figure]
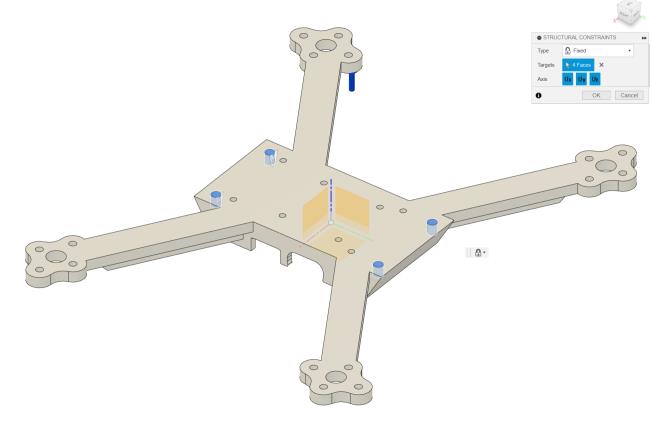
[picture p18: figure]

9. The Pre-Check should now show a green tick- if it doesn’t, click it for a description as to why.

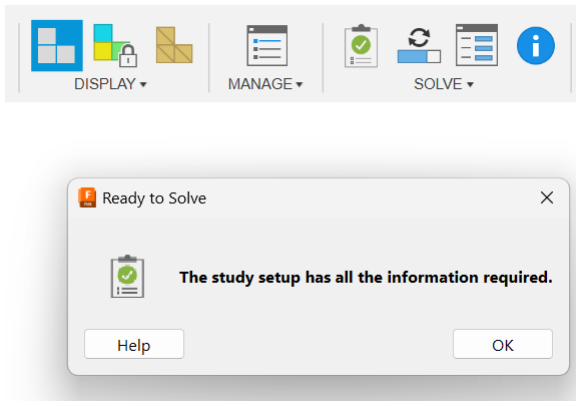
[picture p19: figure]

10. Run the simulation using cloud credits- these cost £1 each, but students get unlimited for free. Make sure not to run this on your personal credit or face financial desolation.

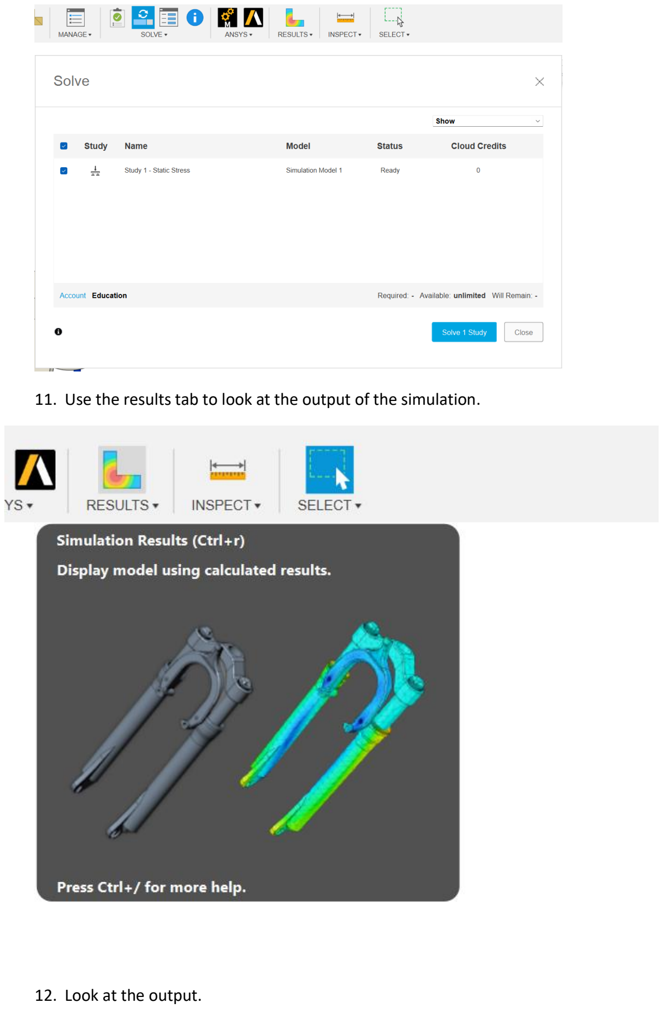
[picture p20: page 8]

11. Use the results tab to look at the output of the simulation.
12. Look at the output.

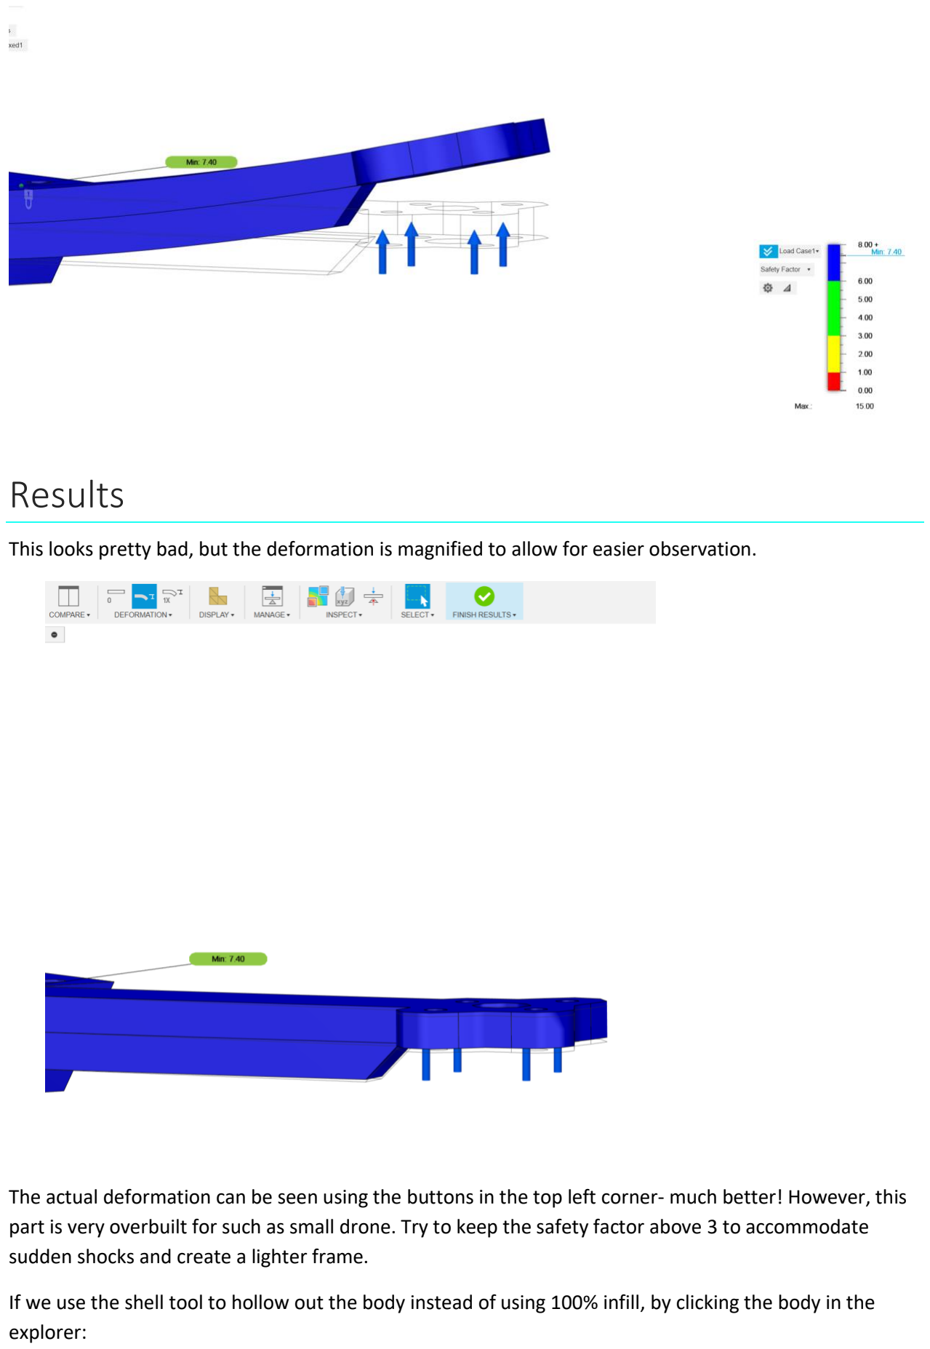
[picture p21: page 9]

# Results

This looks pretty bad, but the deformation is magnified to allow for easier observation.

The actual deformation can be seen using the buttons in the top left corner- much better! However, this part is very overbuilt for such as small drone. Try to keep the safety factor above 3 to accommodate sudden shocks and create a lighter frame.

If we use the shell tool to hollow out the body instead of using 100% infill, by clicking the body in the explorer:

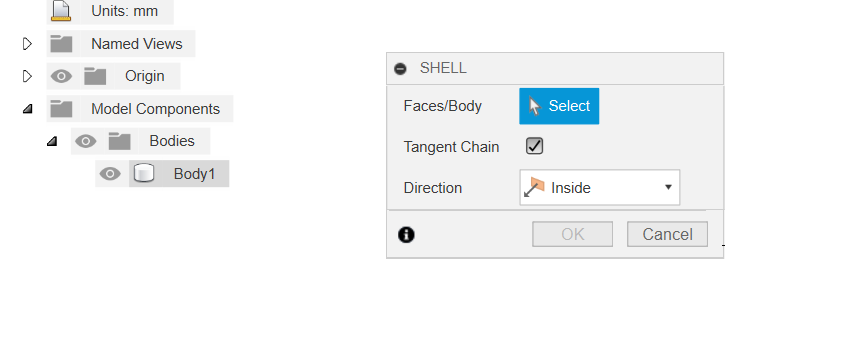
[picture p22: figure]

We get the following after re-running the simulation:

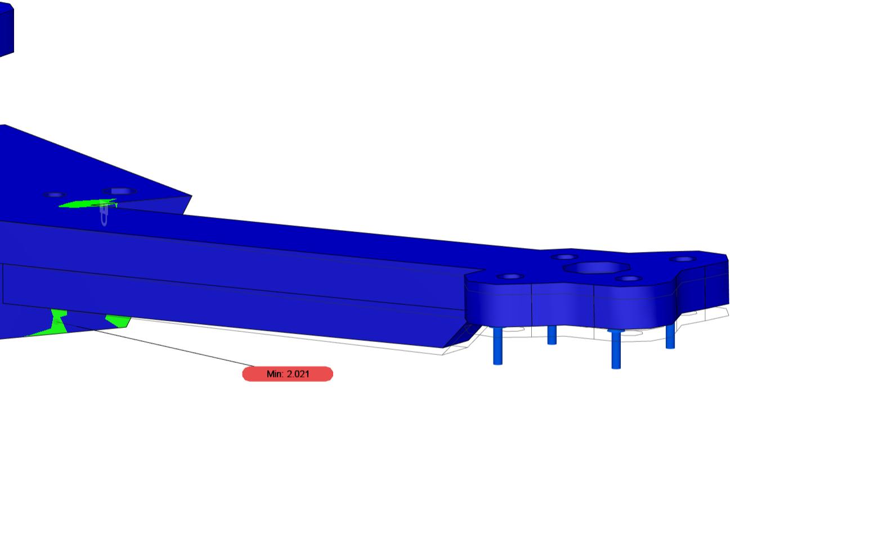
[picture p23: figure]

We can now see how force concentrates at the sharp angles at the base of the arm- this could be easily reduced by adding some fillets, providing further performance gains.

# Advanced Tips

Accurately modelling parts produced via FDM is quite difficult, since the material properties can change with chamber temperature, infill type, layer height, print orientation, nozzle temperature, filament moisture content and so on. As such, it is best to take the results of these simulations as a rough guide instead of an accurate performance prediction.

You can modify material settings under the materials tab. This can be used to account for the weaker bonds between layer lines, to check that the stress doesn’t exceed the delamination forces.

The problem with this is that layer adhesion is determined by many factors, so it can be quite hard to quantify. Overall, it’s best to model your frame to mitigate transmission of force between layer lines.

The process that Fusion 360 uses to hollow out a body is quite different to how it is done in a slicer, so this probably won’t be hugely accurate to recreating the print geometry.

# Event Simulation

A UAV should be designed to not just tolerate in-flight loading, but also dynamic events such as crashes. However, Fusion 360 Event Simulation does not provide accurate results for common FDM materials such as PLA. Another major issue is that in a crash, layer lines and seams are likely to crack and delaminate in unexpected ways. Overall, this makes the results of dynamic simulations quite misleading here. Keep in mind that even if your drone frame can handle the forces in flight easily, all bets are off in a crash.

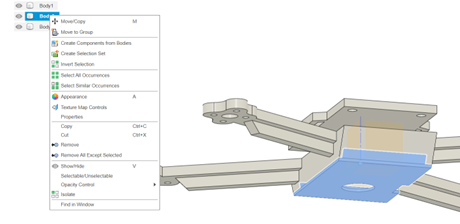
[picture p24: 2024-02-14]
Images/Picture5.png

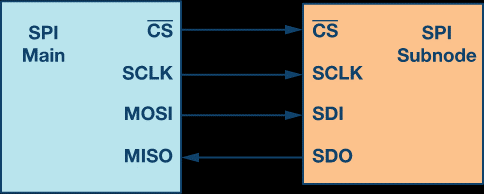
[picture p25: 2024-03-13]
Images/SPI.png

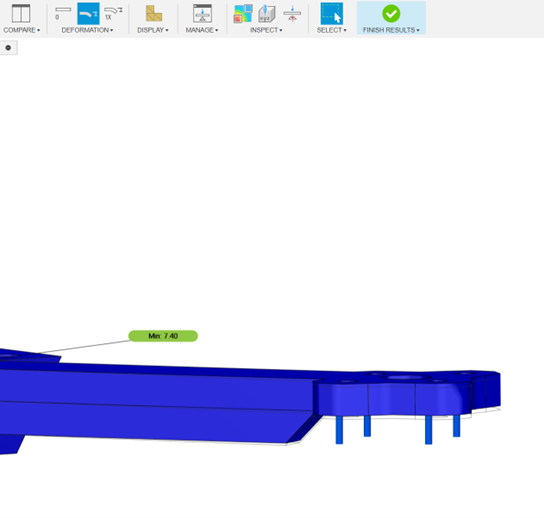
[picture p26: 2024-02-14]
Images/Picture17.png

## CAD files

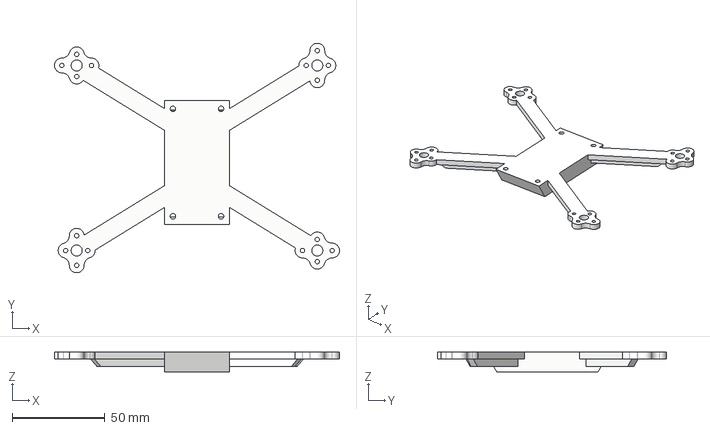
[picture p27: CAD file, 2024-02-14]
workshop2/Parts/MicroDroneFinal v24.step
154.0 x 124.0 x 10.6 mm

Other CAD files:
workshop2/Parts/15A ESC v4.f3d
workshop2/Parts/1806 v2.f3d
workshop2/Parts/AirUnit v1.f3d
workshop2/Parts/Battery v2.f3d

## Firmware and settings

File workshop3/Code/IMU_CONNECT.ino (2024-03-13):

// IMU Check Before Takeoff

#include <SPI.h>

#define MPU6500_NCS 18
#define MPU6500_ID 0x70
#define WHO_AM_I_REG 117
#define READ_BIT_MASK 0x80

SPIClass *IMUHSpi = NULL; //Create a null pointer to our SPI controller. You can imagine this as a "SPI controller box", so we can tell the ESP32S3 "use the controller you find in the box called IMUHSPI" instead of directly telling it "Use SPI controller 2"

void setup() {
  Serial.begin(); //Look ma, no baud rate! You don't actually need to set it with the S3's USB controller, but I'll often set it to 115200 as a force of habit

  delay(500); //A short delay, to let USB serial start before we try to use it
  

  IMUHSpi = new SPIClass(FSPI); //The ESP32 S3 has four SPI busses- two internal, two external. Here, we'll set the null pointer to be refereing to one of the two external ones
  setupIMUSPI(IMUHSpi); //This function sets all of the parameters of the SPI controller to work with the MPU6500

  if (readIMURegister(WHO_AM_I_REG) != MPU6500_ID) { //If the value returned from the name register isn't its name
    Serial.println("IMU not found. Takeoff may result in an unpleasant day."); //Warn the user
    Serial.print("WHO AM I register returned: 0x");
    Serial.println(readIMURegister(WHO_AM_I_REG), HEX); //This might return 0x71. If this is the case, just change the definition at the top of the sketch
    while (1) {; // Halt program on error, so the drone can't do anything funky
    }
  } else {
    Serial.println("IMU found");
  }
}

void loop() {
  // Main loop
}

int readIMURegister(int registerAddress) {
  int readCommand;
  int regData;

  //Put your code here

  return regData;
}

void setupIMUSPI(SPIClass *IMUHSpi) {
  pinMode(MPU6500_NCS, OUTPUT); 
  digitalWrite(MPU6500_NCS, HIGH);

  IMUHSpi->begin(17, 15, 16, 18);  //These are the pins connected to the MPU6500 on the Air Unit. If you hover your mouse over begin, it'll tell you what each does
  IMUHSpi->setFrequency(1000000); //Set the speed to a gentle 1 million bits per second. We'll crank it up to 20 million later
  IMUHSpi->setDataMode(SPI_MODE0);  //This is about what side of the clock you read on, the datasheet for a sensor will tell you which to use
  IMUHSpi->setBitOrder(MSBFIRST); //Send the data Most Significant Bit first. Again, datasheets will tell you how to set this
}
